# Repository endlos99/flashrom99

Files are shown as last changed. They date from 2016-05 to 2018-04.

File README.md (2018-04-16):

FlashROM 99
===========

The *TI 99/4A Flash ROM Cartridge*, or FlashROM 99 for short, is a cartridge
for the TI 99/4A home computer that allows for running ROM cartridge images
stored on an SD card.

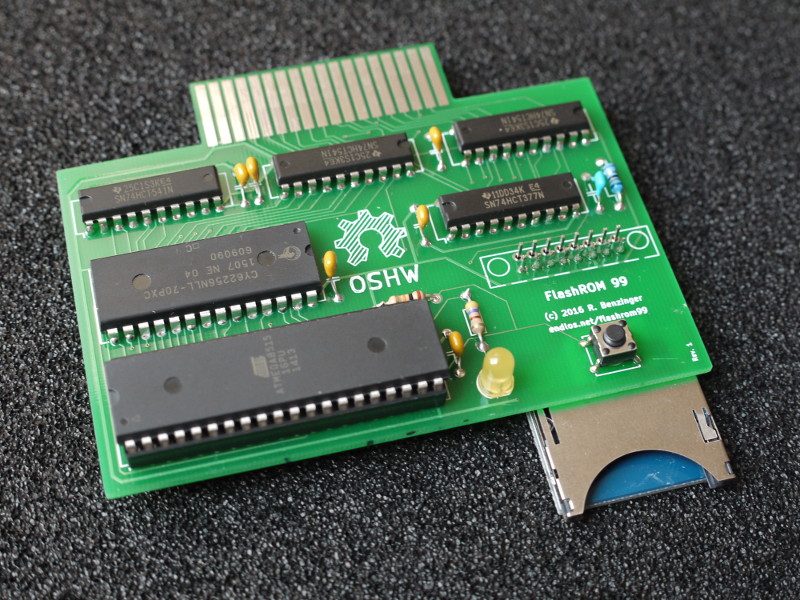
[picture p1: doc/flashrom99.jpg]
The FlashROM 99 Cartridge


The FlashROM 99 supports ROM-only images of up to 32K that use the
write-to-`>60xx` bank switching scheme.  It will not work with programs
using GROMs or CRU-based bank switching.  The cartridge does not require the
Peripheral Expansion Box and runs on both PAL and NTSC consoles.

The project homepage is hosted at [GitHub][1].

FlashROM 99 is released as Open Source Hardware under the
[CERN OHL license][4] and the [GNU GPL license][5].  Both hardware design
files and firmware sources are available on [GitHub][2].

Using the FlashROM 99
---------------------

Using the FlashROM 99 is simple and doesn't require and special hardware or
software.

To begin, copy up to 171 cartridge image files onto an SD or SDHC card.
Switch off the TI 99 and plug in the FlashROM 99, then insert the SD card
into the FlashROM 99.  Switch on the TI 99 and wait until the activity
indicator on the FlashROM 99 is no longer lit.

Press any key to bring up the TI menu screen.  You should see the list of
images found on the SD card.  If the SD card contains more than 8 images, a
`FLASHROM 99` entry is shown instead.  Selecting this entry starts an image
browser where you can page through the list of available images with `,`,
`.`, `SPACE`, and number keys.

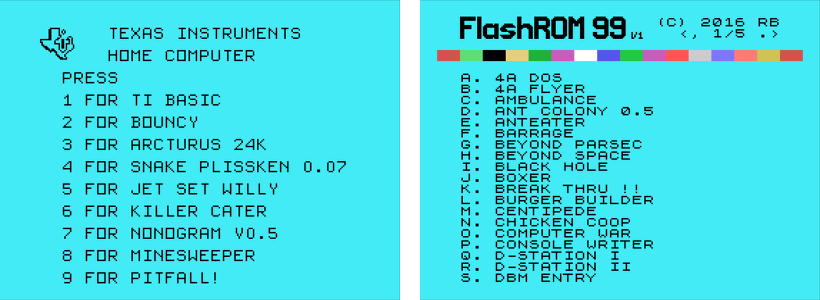
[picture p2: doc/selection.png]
Image selection


Select the image you want to run.  The screen will show a loader animation
while the image loads.  Once the image has been loaded, it will run
automatically.  The SD card is now no longer required and may be removed.

If only one image is found on the SD card, it is loaded immediately without
the need to select it first.

If you want to run a different program from the SD card, reset the TI 99 by
pressing `FCTN-=` and then reset the FlashROM 99 by pushing the reset
button.  If you do not reset the FlashROM 99, the TI menu will show only the
previously selected image.  Alternatively, you can power cycle the console,
which will reset both TI 99 and FlashROM 99.

For detailed usage information please refer to the [FlashROM 99 homepage][1].

Building the FlashROM 99
------------------------

The [GitHub repository][2] contains all hardware design files and software
sources required to build the FlashROM 99.

### Hardware

To assemble the FlashROM 99 you need the following components:

- 1x FlashROM 99 board
- 1x ATmega 8515 (either 8515-16 or 8515L-8)
- 1x 62256 32K SRAM (any speed rating)
- 1x 74HCT377 (LS may also work, but untested)
- 3x 74HCT541 (LS may also work, but untested)
- 6x 100 nF capacitors (e.g., multi-layer ceramic X7R, no electrolytic!)
- 1x 68 Ohm resistor
- 1x 330-470 Ohm resistor (depending on LED used, smaller values will be
     brighter)
- 1x 10 kOhm resistor
- 1x LED (e.g., 5 mm red or yellow)
- 1x micro push button
- 1x SD card module

The FlashROM 99 board was designed with [KiCad][6], a cross platform and
open source electronics design automation suite.  The design files are
stored in `pcb/`.

To simplify the board layout, the design uses an inexpensive SD module that
is readily available online.  Searching for `SD card Arduino` should give
you plenty of hits, including Amazon, ebay, and Pollin.  Make sure to pick a
module that matches the pin-out of the reference module shown below. Note
that the 3.3V input is not used, so any substitutes must be powered by 5V.

You can use any kind of single color LED, but you may have to adjust the 470
Ohm resistor if you choose anything other than red or yellow.

The push button is used to reset the board and will be pushed frequently.
You might choose an angled button if you prefer to push horizontally instead
of vertically.  This will also put less stress on the cart connector.

If the board shows connectors for a 1 nF capacitor next to the 377, do *not*
put this capacitor there, but leave the connectors empty.

When assembling the board make sure to place all ICs properly oriented --
some ICs are upside down!  On the board, the location of pin 1 is indicated
by a small line in the IC outline.  Socketing the ATmega allows for future
software updates.  It is best not to socket the 541s, however, as this will
make inserting the assembled cart into the TI 99 more difficult.

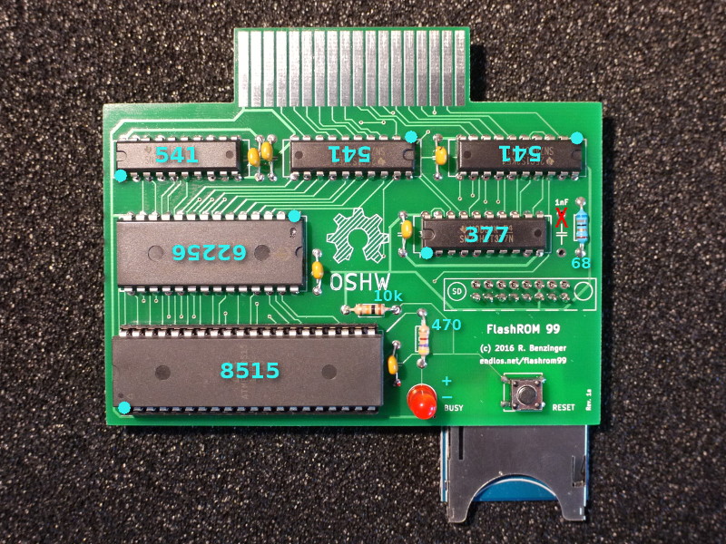
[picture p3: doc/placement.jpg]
Parts Placement


The push button is best soldered to the top of the board so that the bottom
area remains as smooth as possible.  After the button is soldered, put some
insulating tape on its bottom contacts to avoid interference with the SD
module.

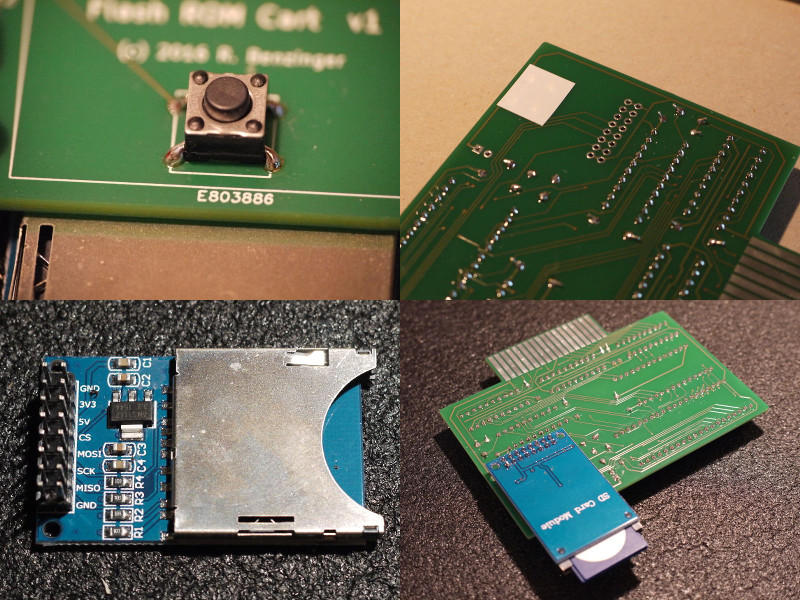
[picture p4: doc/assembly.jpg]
Assembly


Insert the SD module from the bottom and solder either one row of connectors
top so that the metal part of the module is flush with the board.  Some SD
modules have a crooked connector, though, so that a small gap may remain.

If you don't want to build the board yourself feel free to contact the
developer for available sources.

#### Previous Versions

Early versions of the FlashROM 99 used an additional 1 nF capacitor that
resulted in unreliable disk access on some, but not all systems with certain
disk controllers.

Please check to see if the 1 nF capacitor is present on your board.  If so,
simply remove it by desoldering or clipping its wires to improve the
stability of your cart.

If you applied a so-called "disk fix" to your board in the past, you don't
need to undo those changes when removing the capacitor.

### Software

The software for the ATmega 8515 consists of two components.  The `avr/`
folder contains the microcontroller logic for accessing the SD card, filling
the SRAM chip, and controlling the TI bus.

The `ti/` folder contains TI 99 assembly sources for the image menu and the
image browser.  The assembled TMS 9900 machine code is embedded in the
microcontroller code and loaded into RAM during operation.

To build the software, you first need to assemble the menu and browser
program with [`xas99`][3] and convert the generated machine code into C
code:

	$ cd ti/
	$ xas99.py -b -R -I <xdt99>/lib menu.a99
	$ mkmenu.py

Now you can compile the microcontroller code in `avr/`.  The folder contains
a `Makefile` for `avr-gcc` that will make compilation trivial.

	$ cd avr/
	$ make

As an option, you can enable multi-file functionality in the `Makefile`.
This feature, however, will severely extend the scan time for SD cards with
many images.  Only enable multi-file if you plan to use the FlashROM 99 with
no more than about two dozenzs of images per SD card.  To compile with
multi-file, you may have to disable FAT16 support in `avr/lib/pffconf.h` in
case the executable gets too large.

The build yields a `.hex` file that you can flash to the ATmega 8515 using
[`avrdude`][7] or your programmer of choice:

	$ avrdude -p atmega8515 -P /dev/ttyACM0 -c stk500 -U flash:w:flashrom99.hex

Additionally, you need to program the lower fuse bits of the 8515 so that it
runs at 8 MHz:

	$ avrdude -p atmega8515 -P /dev/ttyACM0 -c stk500 -U lfuse:w:0xe4:m

If you're using a different tool chain make sure to set `CKSEL3..0` in the
lower fuse byte to `0100`.  (Note that `0` means "programmed", and `1` means
"unprogrammed").  You can verfify that you're running at the right clock
speed by resetting the FlashROM 99 with no SD card inserted: The LED should
blink about once per second.

Finally, make sure that the bootloader is disabled by checking if higher
fuse bits `BOOTSZ1`, `BOOTSZ0`, and `BOOTRSET` are all set to `1`.  This
should be the default for new 8515s.

In the end, the lower and higher fuse bytes should have values `E4` and
`D9`, respectively.

About the Project
-----------------

The TI 99/4A Flash ROM Cartridge is Open Source Hardware released under the
[CERN OHL license][4], in the hope that TI 99 enthusiasts may find it useful.
Software components are released under the [GNU GPL license][5].

The hardware was designed with the open source electronics design automation
suite [KiCad][6].  The microcontroller code uses a modified version of the
[Petit FatFs][8] library.  Thanks go to Jon Guidry (acadiel) of `hexbus.com`
for designing the original bank switching circuitry for the first TI
multi-carts.

Contributions to both hardware and software are very welcome!  Please email
feedback, support questions, inquiries for parts, and bug reports to the
developer at <r@0x01.de>.  Discussions about the FlashROM 99 happen over at
[AtariAge][9].

[1]: https://endlos99.github.io/flashrom99
[2]: https://github.com/endlos99/flashrom99
[3]: https://endlos99.github.io/xdt99
[4]: http://www.ohwr.org/projects/cernohl/wiki
[5]: http://www.gnu.org/licenses/gpl.html
[6]: http://kicad-pcb.org
[7]: http://www.nongnu.org/avrdude/
[8]: http://elm-chan.org/fsw/ff/00index_p.html
[9]: http://atariage.com/forums/topic/250540-flash-rom-cart

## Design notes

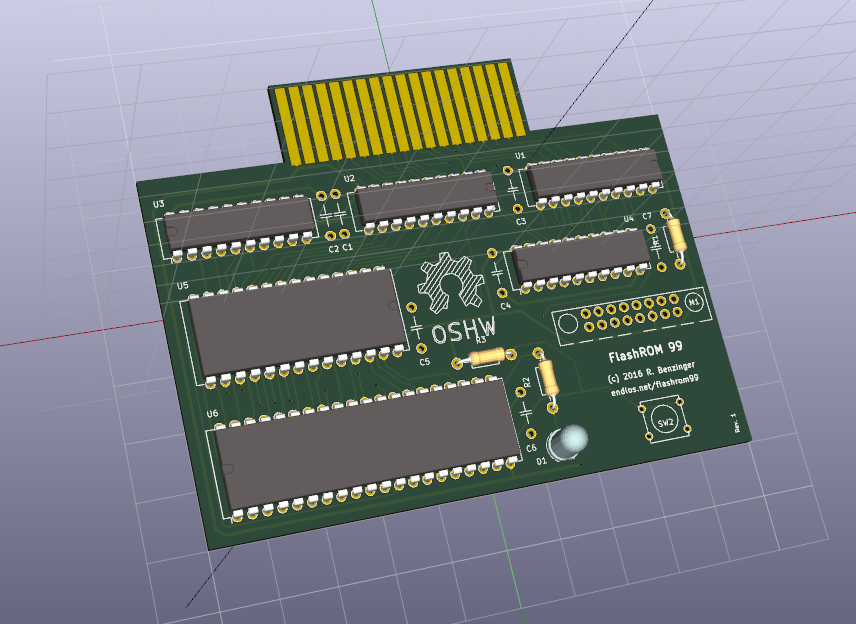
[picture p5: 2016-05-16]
pcb/fr99-preview.png

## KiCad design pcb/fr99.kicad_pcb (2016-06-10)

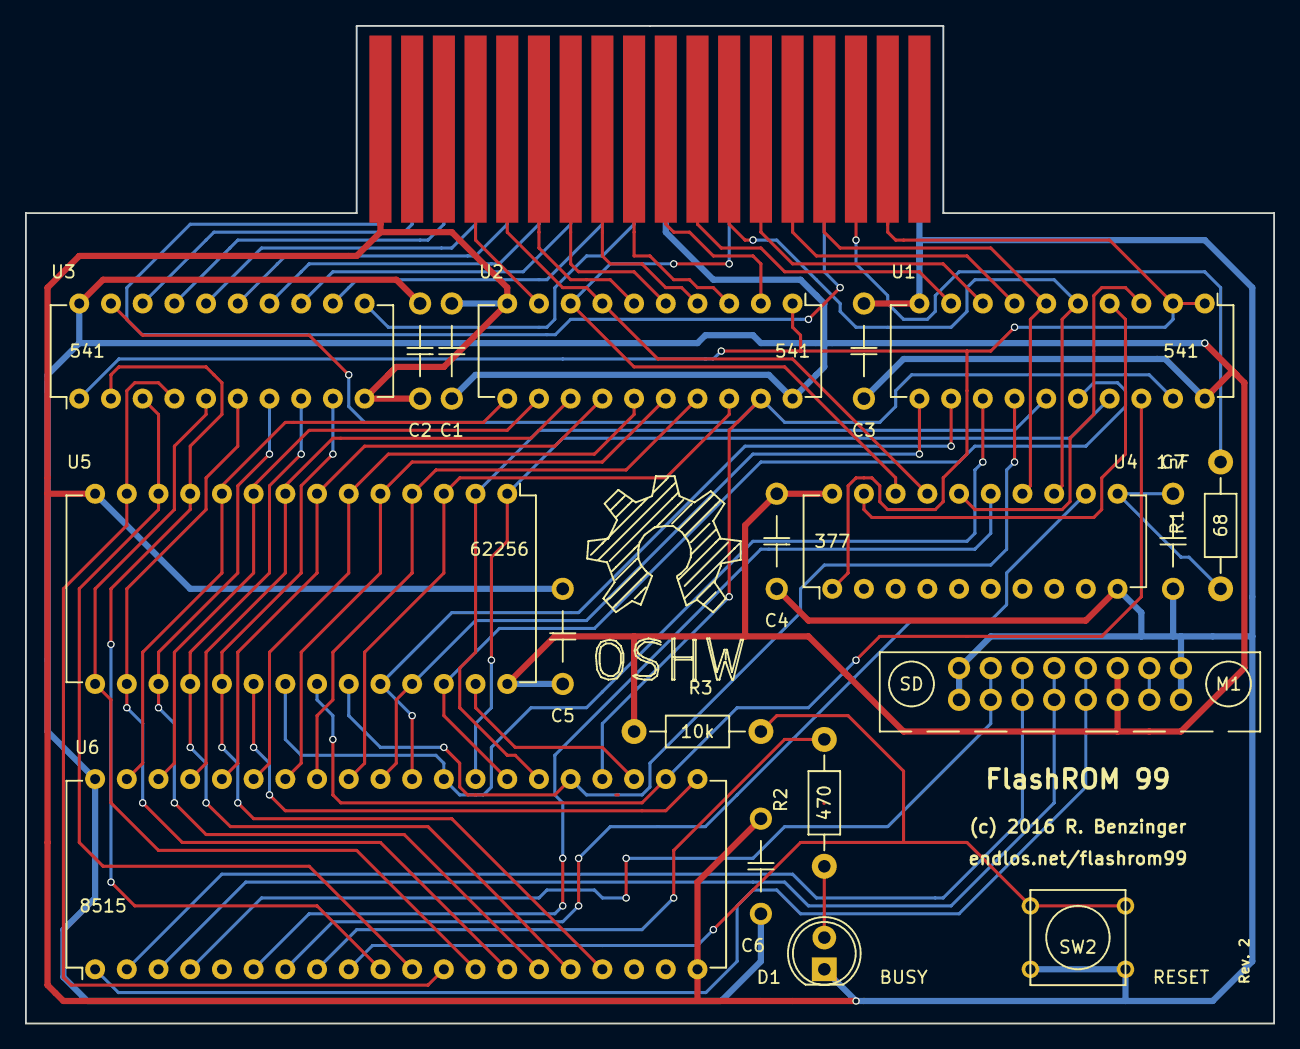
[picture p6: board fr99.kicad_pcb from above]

Board: 2 copper layers, 100.0 x 79.9 mm, 20 parts (0 on the bottom side), 65 nets.

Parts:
C1, C2, C3, C4, C5, C6: 100nF; C_C
C7: 1nF; C_C
D1: BUSY; LED-5MM
M1: SD; SD_MODULE
P1: CONN_02X18; BUS_CART
R1: 68; Resistor_Horizontal_RM10mm
R2: 470; Resistor_Horizontal_RM10mm
R3: 10k; Resistor_Horizontal_RM10mm
SW2: RESET; SW_PUSH_SMALL
U1, U2, U3: 541; DIP-20_W7.62mm
U4: 377; DIP-20_W7.62mm
U5: 62256; DIP-28_W15.24mm
U6: 8515; DIP-40_W15.24mm

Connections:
+5V: C1.2, C2.2, C3.2, C4.2, C5.2, C6.2, M1.6, P1.19, R3.1, U1.20, U2.20, U3.20, U4.20, U5.28, U6.40
/A0: U2.11, U5.10, U6.39
/A1: U2.12, U5.9, U6.38
/A2: U2.13, U5.8, U6.37
/A3: U2.14, U5.7, U6.36
/A4: U2.15, U5.6, U6.35
/A5: U2.16, U5.5, U6.34
/A6: U2.17, U5.4, U6.33
/A7: U2.18, U5.3, U6.32
/A8: U1.11, U5.25, U6.31
/A9: U1.12, U5.24, U6.30
/A10: U1.13, U5.21, U6.29
/A11: U1.14, U5.23, U6.25
/A12: U1.15, U5.2, U6.26
/A13: U1.16, U5.26, U6.27
/A14: U1.17, U5.1, U6.28
/D0: U3.2, U5.11, U6.10
/D1: U3.3, U5.12, U6.11
/D2: U3.4, U5.13, U6.12
/D3: U3.5, U5.15, U6.13
/D4: U3.6, U5.16, U6.14
/D5: U3.7, U5.17, U6.15
/D6: U3.8, U5.18, U6.16
/D7: U3.9, U5.19, U6.17
BUSE: U1.19, U2.19, U3.19, U6.24
GND: C1.1, C2.1, C3.1, C4.1, C5.1, C6.1, C7.2, D1.1, M1.1, M1.8, P1.2, P1.35, SW2.1, U1.10, U2.10, U3.10, U4.10, U5.14, U6.20
unnamed: C7.1, R1.1, U4.11
unnamed: D1.2, R2.1
unnamed: M1.2, U6.4
unnamed: M1.3, U6.2
unnamed: M1.4, U6.3
unnamed: M1.5, U6.1
unnamed: P1.1, P1.29
unnamed: P1.3, U3.18
unnamed: P1.5, U3.17
unnamed: P1.7, U3.16
unnamed: P1.8, U2.9
unnamed: P1.9, U3.15
unnamed: P1.10, U2.7, U4.17
unnamed: P1.11, U3.14
unnamed: P1.12, U2.6
unnamed: P1.13, U3.13
unnamed: P1.14, U2.5
unnamed: P1.15, U3.12
unnamed: P1.16, U2.4
unnamed: P1.17, U3.11
unnamed: P1.18, U2.3
unnamed: P1.20, U2.2
unnamed: P1.22, U1.9
unnamed: P1.23, U2.8, U4.18
unnamed: P1.24, U1.5, U4.13
unnamed: P1.26, U1.8
unnamed: P1.28, U1.7
unnamed: P1.30, U1.6, U4.14
unnamed: P1.32, R1.2
unnamed: R2.2, U6.8
unnamed: R3.2, SW2.2, U6.9
unnamed: U1.3, U4.16
unnamed: U1.4, U4.19
unnamed: U1.18, U5.22, U6.22
unnamed: U4.12, U6.7
unnamed: U4.15, U6.6
unnamed: U5.20, U6.21
unnamed: U5.27, U6.23
ROMS: P1.34, U1.1, U1.2, U2.1, U3.1, U4.1

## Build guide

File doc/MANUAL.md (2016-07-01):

FlashROM 99
===========

The *TI 99/4A Flash ROM Cartridge*, or FlashROM 99 for short, is a cartridge
for the TI 99/4A home computer that allows for running ROM cartridge images
stored on an SD card.

The FlashROM 99 Cartridge

The FlashROM 99 supports ROM-only images of up to 32K that use the
write-to-`>60xx` bank switching scheme.  It will not work with programs
using GROMs or CRU-based bank switching.  The cartridge does not require the
Peripheral Expansion Box and runs on both PAL and NTSC consoles.

FlashROM 99 is released as Open Source Hardware under the
[CERN OHL license][4] and the [GNU GPL license][5].  Both hardware design
files and firmware sources are available on [GitHub][2].

The project homepage is hosted at [GitHub][1].

How to Start with the FlashROM 99
---------------------------------

Using the FlashROM 99 is simple and doesn't require and special hardware or
software.

To begin, copy up to 171 cartridge image files onto an SD or SDHC card.
Switch off the TI 99 and plug in the FlashROM 99, then insert the SD card
into the FlashROM 99.  Switch on the TI 99 and wait until the activity
indicator on the FlashROM 99 is no longer lit.

Press any key to bring up the TI menu screen.  You should see the list of
images found on the SD card.  If the SD card contains more than 8 images, a
`FLASHROM 99` entry is shown instead.  Selecting this entry starts an image
browser where you can page through the list of available images with `,`,
`.`, `SPACE`, and number keys.

Image selection

Select the image you want to run.  The screen will show a loader animation
while the image loads.  Once the image has been loaded, it will run
automatically.  The SD card is now no longer required and may be removed.

If only one image is found on the SD card, it is loaded immediately without
the need to select it first.

If you want to run a different program from the SD card, reset the TI 99 by
pressing `FCTN-=` and then reset the FlashROM 99 by pushing the reset
button.  If you do not reset the FlashROM 99, the TI menu will show only the
previously selected image.  Alternatively, you can power cycle the console,
which will reset both TI 99 and FlashROM 99.

How to Use the FlashROM 99
--------------------------

The following sections provide a detailed look at the FlashROM 99 and
explain all of its features.

### Images

A cartridge image is a binary file containing raw machine code that is
loaded verbatim into the TI 99 cartridge memory.  Many programs are
distributed as image files, and typically have a `.bin` extension.

An additional source for images are cartridge files for emulators.  The MESS
emulator, for example, uses `.rpk` files, which are ordinary ZIP archives
with an unconventional extension.  Images files for Classic 99 can be used
as-is.

Finally, many assemblers such as the [`xas99` cross-assembler][3] can
generate images.  Note that files generated for Editor/Assembler Option 5
*cannot* be used!

Images are single files or multiple files with a common root name:

    helloc.bin
    hellod.bin

If you also see a file ending in `G`

	hellog.bin

then the image is using GROMs and cannot be used for the FlashROM 99.

The FlashROM 99 uses single-file images of up to 32K that must be
"non-inverted", which is the default until noted otherwise by the creator.
If you have an inverted image, you can use the Python script `invert.py` in
the `lib/` folder: An inverted inverted image is a non-inverted image.

Unfortunately, there's no way to determine if an image is inverted or not --
you'll have to try it.  Usually, images ending in `8` are non-inverted, and
images ending in `9` are inverted.  If an image crashes the TI 99, invert it
and see if that works instead.

To use multi-file images, you need to concatenate the individual files into
a single file:

	$ cat hello?.bin > hello.bin                        # Linux and Mac
	c:> copy /b helloc.bin + /b hellod.bin hello.bin    # Windows

Note that the FlashROM 99 can also be built with multi-file support, but as
this deteriorates the startup time this option is not enabled by default.

Images may have more than one program entry to select.  The FlashROM 99
lists all entries of all images.

### SD Cards

The FlashROM 99 supports both SD and SDHC cards of class 4 or higher.
Slower and unrated cards may also work, just try and see.

Cards must be formatted with the FAT16 or FAT32 filesystem.  FAT16 is the
default for new SD cards of up to 2 GB, and FAT32 is the default for new
SDHC cards of 4 GB and up.

Note that some cards seem to have a difficult personality.  For SD cards, it
may help to use FAT32 instead of the FAT16 default.  If you absolutely
cannot get a particular SD/SDHC card to work, just move on and use a
different one.

Image files can be dragged and dropped as-is into the root folder of the SD
card.  Filenames must end in `.bin`, but case is ignored.  Files with other
extensions may be present and are skipped.  For multi-file images, filenames
must have at most 8 characters w/o extension due to filesystem limitations.

The FlashROM 99 handles up to 171 image entries per SD card.  Additional
images will be ignored.

### Operation

The FlashROM 99 is always in one of two modes: _menu mode_ or _image mode_.

When powering up, or after pushing the reset button, the FlashROM 99 is in
menu mode.  In this mode, the TI 99 menu screen shows the list of available
images or the image browser.  Selecting an entry will load the selected
image from the SD card and run it.  Once the image is running, the FlashROM
99 switches to image mode.

In image mode, the FlashROM 99 acts like a ROM cartridge containing the
selected image only.  In this mode, the TI 99 menu screen shows the entries
of the selected image.  Pressing `FCTN-=` will warm reset the console
without affecting the currently stored image.  The only way to return to
menu mode is to push the FlashROM 99 reset button, to power cycle the
console, or to remove and re-plug the FlashROM 99 cartridge.

Note that the SD card is scanned only once in menu mode.  If you swap SD
cards you need to push the reset button to re-read the SD card.  Once in
image mode, the SD card is no longer needed and may be removed until you
want to run a different image.

If only one image is found on the SD card, then it is loaded immediately.
In this case the FlashROM 99 skips menu mode and enters image mode directly.

The activity indicator LED lights up whenever the FlashROM 99 is busy
reading the SD card.  During this time, the entire cartridge is "offline" so
that the TI 99 cannot detect that a cartridge is plugged in.  You may still
operate the console, e.g., work with TI BASIC, while the LED is on, but
depending on your actions you may crash the TI 99.

To summarize, these simple rules of thumb will make sure that you run the
FlashROM 99 without issues:

- After inserting an SD card, push the FlashROM 99 reset button or power
  cycle the console.
- Only push the reset button when the TI 99 title screen is shown.
- Leave both TI 99 and SD card alone whenever the LED is lit and not
  blinking.

It is not possible to damage the FlashROM 99 by incorrect operation,
assuming that shorting contacts or smashing components is way beyond
incorrect operation.

### Compatibility

In general, all cartridge dumps with a compatible banking scheme should work
fine on the FlashROM 99.  Some images converted from other formats, in
particular many modern homebrew programs, may also require a 32K RAM
expansion.

Some programs, however, don't expect to be started by something other than
the TI 99 boot menu, or have difficulties to deal with the remnants of
previously run programs left over by a warm reset.  In rare cases, this may
lead to graphical glitches or other unexpected behavior.

Please refer to the troubleshooting section for a list of games known with
issues.

On some early cartridges, programs that access disk drives may not work
correctly on some systems, in particular with the original TI floppy disk
controller.  Please check [`README.md`](../README.md) to see if you need to
remove a capacitor from the board.

If you find additional images that don't work as intended on the FlashROM
99, please send a note to the developer at <r@0x01.de>, maybe the issue can
be fixed with a software update for the 8515.

How the FlashROM 99 Works
-------------------------

The FlashROM 99 uses a 32K SRAM chip to store a cartridge image of up to
that size.  The TI 99 addresses the SRAM just like it would address a
cartridge ROM chip.

The 377 register maps 8K banks of the 32K SRAM into the cartridge space
`>6000` through `>7FFF`.  The bank switching design used here was originally
developed by Jon Guidry (acadiel) for the [16K multi-cart][6] and has since
been used in many homebrew projects.

The ATmega 8515 microcontroller reads the SD card and writes first the menu
and browser code and then the selected image into the SRAM chip.  The
microcontroller code uses a modified version of the [Petit FatFs][8] library
to make sense of the FAT16/FAT32 filesystems used by SD cards.

Whenever the 8515 is active, the TI 99 must not access the SRAM chip, or the
TI 99 will crash, and either one might get damaged.  Thus, three 541 line
drivers isolate the FlashROM 99 from the cartridge bus whenever the ATmega
is writing to the SRAM.

The 377 also buffers the serial one-way communication from the TI 99 to the
FlashROM 99 that relays the image selection.  The `>6800` address line
transmits the bit data and the `>7000` address line transmits the clock.
Currently, 9 bytes of data are transferred, containing the filename of the
selected image.

While the image loads, the TI 99 reads ROM address `>6000` continuously.
When the cart if offline, this yields value `0000`, but as soon as the cart
goes back online the TI 99 will see the GPL header `AAxx` and jump to the
loaded image.

Troubleshooting the FlashROM 99
-------------------------------

If something isn't working as it should, please try the official test program
first.

Copy [`BANKTEST.BIN`](/images/banktest.bin) as single file onto an SD card and
power up your TI 99 with the FlashROM 99.  Wait for the LED to turn off, then
press any key to bring up the TI menu.

In the menu, you should see an entry for `BANK TEST /x`.  Select the bank test
to see this screen:

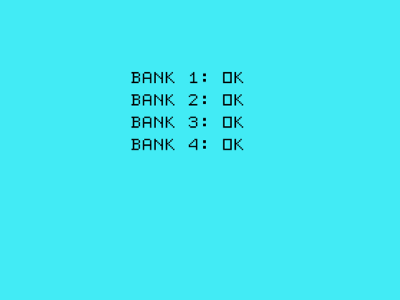
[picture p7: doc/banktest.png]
Bank Test Result


If the bank test doesn't work for you please check the following list for
some suggestions.

#### The TI 99 title screen won't show.

The TI 99 detects the FlashROM 99, but it cannot access the RAM contents.

Check if the 541s are mounted correctly -- two are upside down.  Also look
for bad solder joints, in particular for the 541s and the 8515.  Finally,
verify that you flashed the software to the 8515 correctly.

#### The LED blinks.

If the LED starts blinking, the FlashROM 99 could not read some part of the
SD card:

- 1 blip: bad SD card reader, bad SD card, or wrong filesystem
- 2 blips: corrupt filesystem
- 3 blips: corrupt root directory

Try re-formatting your SD card using FAT32, or try a different card.

#### No menu entries.

The TI 99 starts normally, but the menu shows only TI BASIC.

If the LED doesn't turn on at least briefly when powering up or pushing
reset, some contacts on the card or the 8515 may be bad.

If the LED does light up, make sure that your SD card contains at least one
valid image file, ending in `.bin` or `.BIN`, that is at most 32K big.  You
can use the Python script `lib/mklcart.py` to generate an `.rpk` file to
check any image file in MESS.

#### Programs crash.

The menu shows fine, but running some particular program crashes, either
right away or after some using the program for some time.

You may run an inverted image, an image requiring a GROM, an image with an
incompatible bank switch scheme, or a "fragile" cartridge program.

To fix an inverted image, use the `lib/invert.py` script.  Note that image
files with 8K only cannot be inverted.

A "fragile" program is a program that makes certain assumptions about the
state of scratchpad RAM and VDP RAM when it starts.  Try loading the program
directly to RAM by copying this image file as the only file on an SD card.
This will provide the exact environment the program expects.

If this doesn't help, the image may be incompatible.  Please send a note to
the developer at <r@0x01.de> for further analysis.

#### Programs don't work properly.

Some functionality of the program doesn't work as expected.

Some games don't expect to be started by another program or to find the
remnants of previously run programs.  This may lead to graphical glitches or
other unexpected behavior.

Try restarting the program by pressing `FCTN-=` and selecting it from the
menu again to eliminate most issues.  Alternatively, put the image as the
only image on the SD card so that it is loaded directly.

If this doesn't help, please send a note to the developer at <r@0x01.de> for
further analysis.

#### Programs with known issues.

These programs are known to have some flaws when run on the FlashROM 99:

- Console Writer: Input line shows dotted pattern.

Note that for now, this list refers to particular images tested.  There
might be different images of those programs that work.

Where to Get the FlashROM 99
----------------------------

The [GitHub repository][2] contains all hardware design files and software
sources required to build the FlashROM 99 yourself.

If you want to build a FlashROM 99, you can purchase a professionally made
PCB board for €10 and a preprogrammed 8515 for €5 plus shipping and
handling.  Alternatively, you can get a fully assembled FlashROM 99
cartridge for €45 plus shipping and handling.  Please contact the developer
at <r@0x01.de> for further information.

About the Project
-----------------

The TI 99/4A Flash ROM Cartridge is Open Source Hardware released under the
[CERN OHL license][4], in the hope that TI 99 enthusiasts may find it useful.
Software components are released under the [GNU GPL license][5].

The hardware was designed with the open source electronics design automation
suite [KiCad][7].  The microcontroller code uses a modified version of the
[Petit FatFs][8] library.  Thanks go to Jon Guidry (acadiel) of `hexbus.com`
for designing the original bank switching circuitry for the first TI
multi-carts.

Contributions to both hardware and software are welcome.  Please email
feedback, support questions, inquiries for parts, and bug reports to the
developer at <r@0x01.de>.  Discussions about the FlashROM 99 happen over at
[AtariAge][9].

[1]: https://endlos99.github.io/flashrom99
[2]: https://github.com/endlos99/flashrom99
[3]: https://endlos99.github.io/xdt99
[4]: http://www.ohwr.org/projects/cernohl/wiki
[5]: http://www.gnu.org/licenses/gpl.html
[6]: http://www.hexbus.com/TI-99_4A_Home_Computer_Page/Hardware_Projects.html
[7]: http://kicad-pcb.org
[8]: http://elm-chan.org/fsw/ff/00index_p.html
[9]: http://atariage.com/forums/topic/250540-flash-rom-cart

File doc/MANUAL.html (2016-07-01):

# FlashROM 99

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

The FlashROM 99 Cartridge

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

FlashROM 99 is released as Open Source Hardware under the CERN OHL license (http://www.ohwr.org/projects/cernohl/wiki) and the GNU GPL license (http://www.gnu.org/licenses/gpl.html). Both hardware design files and firmware sources are available on GitHub (https://github.com/endlos99/flashrom99).

The project homepage is hosted at GitHub (https://endlos99.github.io/flashrom99).

## How to Start with the FlashROM 99

Using the FlashROM 99 is simple and doesn't require and special hardware or software.

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

Image selection

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

## How to Use the FlashROM 99

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

### Images

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

Finally, many assemblers such as the xas99 cross-assembler (https://endlos99.github.io/xdt99) can generate images. Note that files generated for Editor/Assembler Option 5 cannot be used!

Images are single files or multiple files with a common root name:

helloc.bin
hellod.bin

If you also see a file ending in G

hellog.bin

then the image is using GROMs and cannot be used for the FlashROM 99.

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

To use multi-file images, you need to concatenate the individual files into a single file:

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

### SD Cards

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

### Operation

The FlashROM 99 is always in one of two modes: menu mode or image mode.

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

### Compatibility

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

Please refer to the troubleshooting section for a list of games known with issues.

On some early cartridges, programs that access disk drives may not work correctly on some systems, in particular with the original TI floppy disk controller. Please check README.md to see if you need to remove a capacitor from the board.

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

## How the FlashROM 99 Works

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

The 377 register maps 8K banks of the 32K SRAM into the cartridge space >6000 through >7FFF. The bank switching design used here was originally developed by Jon Guidry (acadiel) for the 16K multi-cart (http://www.hexbus.com/TI-99_4A_Home_Computer_Page/Hardware_Projects.html) and has since been used in many homebrew projects.

The ATmega 8515 microcontroller reads the SD card and writes first the menu and browser code and then the selected image into the SRAM chip. The microcontroller code uses a modified version of the Petit FatFs (http://elm-chan.org/fsw/ff/00index_p.html) library to make sense of the FAT16/FAT32 filesystems used by SD cards.

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

## Troubleshooting the FlashROM 99

If something isn't working as it should, please try the official test program first.

Copy BANKTEST.BIN as single file onto an SD card and power up your TI 99 with the FlashROM 99. Wait for the LED to turn off, then press any key to bring up the TI menu.

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

Bank Test Result

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

#### The TI 99 title screen won't show.

The TI 99 detects the FlashROM 99, but it cannot access the RAM contents.

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

#### The LED blinks.

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

Try re-formatting your SD card using FAT32, or try a different card.

#### No menu entries.

The TI 99 starts normally, but the menu shows only TI BASIC.

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

#### Programs crash.

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

#### Programs don't work properly.

Some functionality of the program doesn't work as expected.

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

#### Programs with known issues.

These programs are known to have some flaws when run on the FlashROM 99:

- Console Writer: Input line shows dotted pattern.

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

## Where to Get the FlashROM 99

The GitHub repository (https://github.com/endlos99/flashrom99) contains all hardware design files and software sources required to build the FlashROM 99 yourself.

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

## About the Project

The TI 99/4A Flash ROM Cartridge is Open Source Hardware released under the CERN OHL license (http://www.ohwr.org/projects/cernohl/wiki), in the hope that TI 99 enthusiasts may find it useful. Software components are released under the GNU GPL license (http://www.gnu.org/licenses/gpl.html).

The hardware was designed with the open source electronics design automation suite KiCad (http://kicad-pcb.org). The microcontroller code uses a modified version of the Petit FatFs (http://elm-chan.org/fsw/ff/00index_p.html) library. Thanks go to Jon Guidry (acadiel) of hexbus.com for designing the original bank switching circuitry for the first TI multi-carts.

Contributions to both hardware and software are welcome. Please email feedback, support questions, inquiries for parts, and bug reports to the developer at r@0x01.de. Discussions about the FlashROM 99 happen over at AtariAge (http://atariage.com/forums/topic/250540-flash-rom-cart).

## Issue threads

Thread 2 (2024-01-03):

no info on pcb board size

vwbug2007, 2024-01-03:
hmmmm i dont know what to input pcb board size in pcbway quote ....needs l by w in mm

endlos99, 2024-01-06:
The board is 100 mm x 80 mm.

Closed 2024-01-06.

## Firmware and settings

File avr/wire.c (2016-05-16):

/*
 * wire.c: low-level signal handling
 */

#include <avr/io.h>
#include <util/delay.h>

#include "wire.h"


/*
 * pins
 *
 * A7  A7         B7  LED       C7  A14       D7  D7        
 * A6  A6         B6  IMG EN    C6  A13       D6  D6        
 * A5  A5         B5  IMG DAT   C5  A12       D5  D5        
 * A4  A4         B4  --        C4  A11       D4  D4        
 * A3  A3         B3  SD MISO   C3  BUS EN    D3  D3        
 * A2  A2         B2  SD MOSI   C2  RAM WE    D2  D2        E2  A10
 * A1  A1         B1  SD SCK    C1  RAM RE    D1  D1        E1  A9
 * A0  A0         B0  SD CS     C0  RAM CE    D0  D0        E0  A8
 */

#define SENDER_BYTES  9   // FILENAME \0


/*
 * isolate FlashROM 99 from TI cart bus
 */

void disableBus()
{
  // take control and set up SRAM
  PORTC =
    (1 << PC3) |  // isolate cart bus
    (1 << PC2) |  // no RAM writes
    (1 << PC1) |  // no RAM reads
    (0 << PC0);   // enable SRAM chip
  DDRC = 0xff;

  // configure outputs
  DDRA = 0xff;
  DDRB = 0x80;  // SD managed by PFF library
  DDRD = 0xff;
  DDRE = 0x07;

  // LED indicator on
  PORTB |= 1 << PB7;  // LED high = bus disabled
}


/*
 * deactivate all AVR outputs and connect SRAM to TI cart bus
 */

void enableBus()
{
  // prepare SRAM for ROM mode
  PORTC |=
    (1 << PC2) |  // ROM mode: no writes
    (1 << PC1) |  // ROMS* drives RAM RE
    (1 << PC0);   // disable RAM during hand-over
  // alternatively, ROMS* drives CE, RE permanently active

  // disable all bus outputs
  DDRA = 0x00;
  DDRB = 0x80;  // LED remains output
  DDRC = 0x09;  // BUS, RAM CE remain output
  DDRD = 0;
  DDRE = 0;

  // tri-state unused pins
  PORTA = 0x00;
  PORTB = 0x00;  // LED indicator off
  PORTC &= 0x0f;
  PORTD = 0x00;
  PORTE = 0x00;
  
  // release control
  PORTC &= ~((1 << PC3) |
	     (1 << PC0));  // SRAM permanently enabled
}


/*
 * set SRAM address and data
 */

void setRAM(uint16_t addr, uint8_t byte)
{
  // RAM WE still high

  // address: (MSB)  X C7 ..... C4 E2 .. E0 A7 ................. A0 (LSB)
  //                15 14 13 12 11 10  9  8  7  6  5  4  3  2  1  0
  PORTC = (PORTC & 0x0f) | ((addr & 0x7800) >> 7);  // A14 .. A11
  PORTE = (addr & 0x0700) >> 8;  // A10 .. A8
  PORTA = addr & 0x00ff;  // A7 .. A0

  PORTD = byte;  // data

  PORTC &= ~(1 << PC2);  // RAM WE low
  _delay_us(1);
  PORTC |= 1 << PC2;  // RAM WE high
}


/*
 * read TI data via serial connection (MSB to LSB)
 * - next/done:  CLR @>6000
 * - send 0:     CLR @>7000
 * - send 1:     CLR @>7800
 */

void receiveData(uint8_t *buffer)
{
  uint8_t b;

  // get to known state (IMGEN low), initial CLR @>6000 comes too late
  while (PINB & (1 << PINB6));

  // read serial data from TI
  for (uint8_t i = 0; i < SENDER_BYTES; ++i) {
    b = 0;
    for (uint8_t j = 0; j < 8; ++j) {
      // wait for bit (IMGEN high)
      while (!(PINB & (1 << PINB6)));
      _delay_us(2);
      // read bit
      b = (b << 1) + (PINB & (1 << PINB5) ? 1 : 0);
      // wait until IMGEN low again
      while (PINB & (1 << PINB6));
    }
    *buffer++ = b;
  }
}


/*
 * fatal error: blink LED
 */

void flash_error(const uint8_t count)
{
  while(1) {
    for (uint8_t i = 0; i < count; ++i) {
      PORTB |= 1 << PB7;
      _delay_ms(300);
      PORTB &= ~(1 << PB7);
      _delay_ms(300);
    }
    _delay_ms(500);
  }
}


/* --- debugging -------------------------------------------------- */

#ifdef DEBUG

/*
 *  diagnostic output by attaching 7 segment display to pins Ax
 *  segment a = A6 ... g = A0
 */

const uint8_t segment[] = {
  //  abcdefg
  0b1111110,  // 0
  0b0110000,
  0b1101101,
  0b1111001,
  0b0110011,
  0b1011011,
  0b1011111,
  0b1110000,
  0b1111111,
  0b1111011,  // 9
  0b1110111,  // a
  0b0011111,
  0b1001110,
  0b0111101,
  0b1001111,
  0b1000111,  // f
  0b0000000   // all off
};


/*
 *  display byte nybble by nybble
 */

void show(uint8_t n)
{
  PORTA = segment[n >> 4];
  _delay_ms(700);
  PORTA = segment[n & 0xf];
  _delay_ms(700);
  PORTA = 0;
  _delay_ms(900);
}

#endif

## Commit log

2016-05-16 FR99: initial release of FlashROM 99 v1.0
    [fr99.kicad_pcb, fr99.sch]
2016-06-05 PCB: added values to silkscreen
    [fr99.kicad_pcb]
2016-06-10 FR99: added sample images
2016-06-10 PCB: fixed bank switch (disk access issue)
    [fr99.kicad_pcb, fr99.sch]
2016-11-06 PCB: added Gerber files
    [fr99.gbl, fr99.gbs, fr99.gko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]
2018-04-16 DOC: fix fuse bytes description

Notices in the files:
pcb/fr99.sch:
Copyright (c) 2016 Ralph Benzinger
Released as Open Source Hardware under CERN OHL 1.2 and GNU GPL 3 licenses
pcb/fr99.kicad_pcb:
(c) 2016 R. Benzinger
